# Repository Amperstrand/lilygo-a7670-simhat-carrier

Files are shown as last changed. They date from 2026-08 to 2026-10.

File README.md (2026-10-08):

# LILYGO T-A7670X + T-SimHat Combined Carrier

Parametric, 3D-printable internal electronics carrier that holds a
**LILYGO T-A7670X ESP32 modem board** and a **LILYGO T-SimHat (single-relay
variant)** side-by-side — mounted separately, wired together with jumpers —
for subsequent installation inside a waterproof enclosure.

Fully scripted in **Python + CadQuery**, driven by **manufacturer STEP/DXF
geometry** (no guessed dimensions), validated programmatically, and
regenerable with one command.

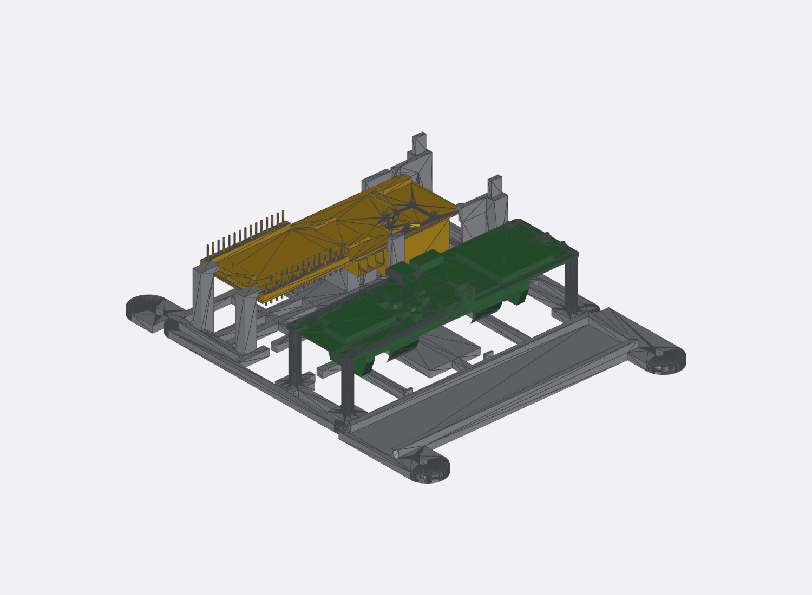
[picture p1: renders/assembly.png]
Assembly render


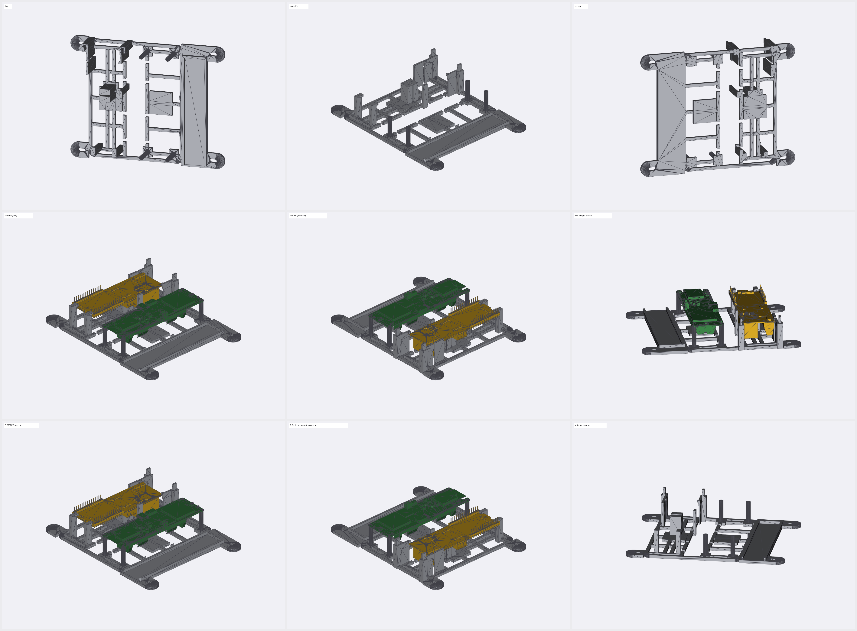
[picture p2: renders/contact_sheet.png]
Contact sheet


*T-SimHat (amber) flipped — relay down, headers up. T-A7670X (green) on
25 mm standoffs (18650 + holder underneath). LTE sticker-antenna tray on
the right edge (free air, coax clips on the frame rail). Full carrier
162 × 127.5 mm.*

## Explore in 3D

- **Interactive in-browser**: open any `.stl` on GitHub — it renders in a
  built-in 3D viewer you can rotate: [carrier](exports/lilygo_a7670_simhat_carrier.stl),
  [low-profile template](exports/lilygo_a7670_simhat_carrier_lowprofile.stl),
  [clip coupon](exports/simhat_clip_test.stl), [A7670 section](exports/sections/a7670_section.stl),
  [SimHat cage section](exports/sections/simhat_cage_section.stl).
- **Download & spin anywhere**: [assembly GLB](exports/lilygo_a7670_simhat_assembly.glb)
  and [carrier GLB](exports/lilygo_a7670_simhat_carrier.glb) open in Windows
  3D Viewer, macOS Preview, Blender, https://gltf-viewer.donmccurdy.com.
- **Renders**: served from GitHub Pages (CI rebuilds and redeploys them on
  every push — they are generated, not tracked): labeled views incl.
  per-board close-ups (`a7670_closeup.png`, `simhat_closeup.png`) and the
  contact sheet, at
  `https://amperstrand.github.io/lilygo-a7670-simhat-carrier/<name>.png`.
  Photo-textured hybrids are audited by `scripts/audit_photobake.py`
  (plane placement from placed STEP solids + fiducial centroids vs CAD
  truth).

## Key measured dimensions (from manufacturer CAD)

| Item | Value | Source |
|---|---|---|
| T-A7670X PCB | 33.071 × 110.54 × 1.2 mm | STEP cross-section + DXF dim `33.071` |
| T-A7670X mounting holes | 4 × Ø1.73 mm, 27.71 × 105.59 mm grid | DXF hole-callout dims, cross-checked vs STEP cylinders |
| T-A7670X mounting | **M1.6 screws into printed pilots** (default after the v0.3 print; `A7670_MOUNT="snap_plugs"` restores the screwless christmas-tree plugs) | Ø1.70 STEP holes, true centers measured off placed geometry |
| T-A7670X battery | 18650 + holder under board → 25 mm standoffs | user hardware + product docs |
| T-SimHat PCB | 33.0 × 94.8 × **1.0 mm** | STEP cross-section (verify with calipers: some batches 1.6) |
| T-SimHat mounting holes | **none** (hence snap-in cage) | STEP |
| T-SimHat relay | OMRON G5LE-class, 16.5 × 22.7 × 18.25 mm, single relay confirmed in STEP | STEP solids |
| LTE sticker antenna | ~110 × 20 mm sticker, 10–15 cm coax (user-measured; parametric `ANT_W`/`ANT_SLIDE`/`ANT_CABLE_L`) | — |

## Layout: rotated for short jumpers

The A7670X is mounted rotated 180° (`A7670_ROT_180`) so its pin-header
rails land at the same end as the SimHat's up-facing sockets: jumpers
cross the 16 mm wiring channel at ~15–25 mm instead of ~120 mm, and the
SMA antenna jacks sit a ~6 mm coax hop from the side-tray clips.

## Antenna side tray

The bundled full-band LTE sticker (~110 × 20 mm, SMA coax) slides into an
open tray on the +X frame edge, **between the two +X M3 ear slots** — free
air instead of under the 18650, so routing the coax up is trivial: it
drops into grooved posts on the tray's inner wall and runs along the
frame edge to the SMA jacks. Position was chosen by elimination, each
option boolean- or envelope-disproven: mid-channel (cage hardware cuts
the clear width to 17.3 mm vs 21.2 needed), a shelf over the SimHat
(blocks its removal lift), an end tray (237 mm vs the 175 mm bed).
**Caliper your sticker and set `ANT_W`/`ANT_SLIDE` before printing.**

## Print variants (all parametric)

| Variant | File | Print height | Purpose |
|---|---|---|---|
| **Calibration mini-coupon** | `exports/lilygo_calicheck_mini.3mf` | ~28 mm local, ~21 g, **~15 min** | **FIRST PRINT**: M1.6 pilot-hole ladder, SimHat thickness stair, antenna width slits, real snap-clip bay — calibrates every printer-dependent number before anything bigger |
| **Gridfinity fit-check tray** | `exports/lilygo_fitcheck_tray_gridfinity.3mf` | 33 mm pins / 7 mm body, ~17 g | second print: gauge pins verify the A7670 hole pattern with battery installed; SimHat outline + fence gauges; antenna channel; then clips onto any Gridfinity 3×4 baseplate |
| Full carrier | `exports/lilygo_a7670_simhat_carrier.stl` | ~34 mm, ~51 g | production holder (M1.6 screws, snap-caged SimHat, +X antenna tray) |
| Low-profile template | `exports/lilygo_a7670_simhat_carrier_lowprofile.stl` | **9 mm** | batteryless screw-fit + cage-outline check (relay/holder hang through the open frame); wall-mountable via M3 ear slots. Build: `CARRIER_PROFILE=low python scripts/build.py` |
| Snap coupon | `exports/simhat_clip_test.stl` | ~35 mm bay | pick XY clearance 0.20–0.50 (superseded for feel by the mini-coupon bay, still useful for clearance sweep) |
| Sections | `exports/sections/*.stl` | varies | iterate one region cheaply (A7670 plate / SimHat cage / antenna tray); volume-partition of the full carrier |

Print order: **full carrier** (one calibration pass already done; reprint the
calicheck mini only if you change `SIMHAT_PCB_XY_CLEAR` or the fence bite).
Design intent + audit table: `docs/design_spec.md`.

## Port access (validated)

Keep-clear service envelopes with zero printed-material interference:
USB-C plug, both SMA antenna connectors, SIM-tray swap zone, battery JST,
SimHat jumper-socket zone, relay/terminal cavity, the 18650 battery
keep-out under the A7670X, and auto-derived SimHat side/end-exit mating
envelopes (P1/P2, CAN/RS485 housings, terminal wire entry) — see
`analysis/interference_report.json` and `cad/connectors.py`.

## Status

`v0.4.0-validated` — 35/35 checks (full) + 28/28 (low) pass. v0.3 print
feedback addressed: M1.6 screws default, biting fence + snug end play
(rattle), fences off P1/CAN (mating-envelope enforced), antenna in the
+X side tray with coax clips. Carrier ~51 g PETG, 162 × 127.5 mm
(A1-mini safe).

## How the T-SimHat is held

No screws, no load on components:

- **4 support pads** (6 × 6 mm) contact **bare laminate only**, at grid
  positions verified clear of all 77 component solids in the STEP model
- **Fixed capture lip** at the far end (2 segments) hooks over the PCB top edge
- **2 flexible corner clips** at the near end snap over the PCB edge;
  flexure bends **in the XY print plane** (14 mm arms, ~1.6 % strain — PETG-safe)
- **3 fences** locate X/Y; board cannot slide or rotate
- **Removal:** press both release tabs → lift clip end 0.15 mm → slide out
  from under the lip (validated collision-free, incl. relay/SMD sweep paths)

## Quick start

```bash
uv venv .venv && uv pip install --python .venv/bin/python cadquery ezdxf trimesh numpy pillow lxml
.venv/bin/python scripts/analyze_step.py   # already run; regenerates analysis/*.json
.venv/bin/python scripts/build.py          # rebuilds exports/ (full + low) + renders/ + GLB/3MF
.venv/bin/python scripts/validate.py       # 18 checks -> analysis/interference_report.json
CARRIER_PROFILE=low .venv/bin/python scripts/validate.py   # low-profile checks (11)
```

## Printing

- **First print the coupon:** `exports/simhat_clip_test.stl` — four labeled
  clearance variants (0.20/0.30/0.40/0.50 mm, notch-counted). Pick the best
  fit, then set `SIMHAT_PCB_XY_CLEAR` in `cad/parameters.py` and rebuild.
- Full carrier: flat on the plate as modeled, no supports needed.
  PETG starting settings in `docs/print_settings.md`.

## Reference provenance

Manufacturer geometry lives in `references/` (MIT-licensed, © LILYGO),
copied from the forks in `vendor/` — see `references/PROVENANCE.md` for
exact upstream commits. Forks: `Amperstrand/T-SimHat`,
`Amperstrand/LilyGo-Modem-Series` (upstream: `Xinyuan-LilyGO/...`).

## Layout

```
cad/parameters.py     every dimension in one place (measured values load from analysis/*.json)
cad/holder.py         parametric model: base frame, standoffs, snap cage, ears
scripts/analyze_step.py   STEP -> geometry JSON (holes, PCB slab, components)
scripts/analyze_dxf.py    DXF dimension cross-check
scripts/build.py      regenerates exports/ and renders/
scripts/validate.py   interference, watertight, envelope, features, removal
exports/              carrier + coupon STL/STEP, assembly STEP
analysis/             machine-readable geometry + validation reports
docs/                 design decisions, assembly, print settings
```

All parameters — standoff height, board gap, clip geometry, ear positions,
pad locations, clearances — are in `cad/parameters.py`.

## Related project: Nucula NFC board enclosure

[`Amperstrand/nucula-enclosure`](https://github.com/Amperstrand/nucula-enclosure) —
the first outward port of this repo's methodology to a second measurement
front-end (KiCad instead of manufacturer STEP/DXF): a parametric,
3D-printable enclosure for the **Nucula board** (ESP32-C3 + NFC coil),
57/57 boolean checks green in its own CI. This repo's AGENTS.md prompt
library is the playbook it was built from — treat the two repos as
targets #1 and #2 of the same AI-assisted case-building framework.

## Repository

- GitHub: `Amperstrand/lilygo-a7670-simhat-carrier` (public)
- Branch: `cad/combined-carrier-v1`

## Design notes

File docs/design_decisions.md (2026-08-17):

# Design decisions

Rationale for the load-bearing choices. Dimensions live in
`cad/parameters.py`; measurements in `docs/reference_geometry.md`.

## Layout: side-by-side, long edges parallel

- A7670X 33.07 × 110.54 + SimHat 33.0 × 94.8 stacked end-to-end would exceed
  205 mm in Y — too long. Side-by-side with a 12 mm wiring channel:
  129.1 × 127.5 mm footprint, fits the 175 mm A1-mini safety envelope with
  >45 mm margin, and both boards stay serviceable from above.
- A7670X on +X, SimHat on −X; clip end of the SimHat faces the frame
  centerline so release tabs are between the boards (reachable, and jumper
  wires from the up-facing headers drop straight into the channel).

## A7670X mounting: M1.6 screws into printed pilots

- PCB holes are Ø1.73 mm (DXF-verified) → M1.6 is the honest fit. M2/M3
  would ream the board. Cross-checked STEP (Ø1.70 cylinders) vs DXF
  (Ø1.7296 callouts) — same centers.
- Pilot Ø1.30 × 8.5 mm deep in Ø4.6 bosses: self-tapping PETG thread,
  ~1.65 mm wall around the pilot. Blind pilots (1.5 mm floor) so screws
  never touch the enclosure below.
- Standoff height 13 mm: base 3.2 + bottom shield 8.5 + ~1.3 mm air. The
  parameter exists because boards with soldered 16 mm stacking headers need
  21 mm — one-line change.
- Board located by its 4 screws (not rails): no XY clearance fights, and
  unscrew → lift free is unobstructed (validated).

## T-SimHat: flipped, laminate-supported, snap-retained

Why flipped (relay down, headers up): the project wires the boards with
jumpers — headers must face up; relay/terminal side is the tall side that
benefits from a cavity; terminal-block screws face down but are only
touched at install time (mount carrier on enclosure screws AFTER wiring, or
leave relay-side access; see assembly doc).

Retention concept per requirements — open frame, no tray:

- **4 support pads** (6×6 mm) on bare laminate at v 34.5/42.0, u ±3.5 — the
  only ≥7 mm free window on both strips when checked against **all 77**
  component solids (first attempt used top-10 zones and validation caught
  real SMD collisions — kept the full-solid check).
- **Fixed capture lip** at the far end (v=94.8), 2 segments at u −13.5…−9
  and 9…13.5, engaging 2.6 mm over the PCB top. Segmented to keep the
  up-facing far-end SMDs (v 78.9–85.7) and header sockets (v 54–94.7,
  u ±14…16.5) clear; the two chosen windows are bare edge laminate.
- **2 corner clips** at the near end engage the PCB edge 1.0 mm over the
  top face. Flexure is **in the XY plane** (arm bends about Z): printed
  layers stay in-plane → maximum layer adhesion, no Z-axis peeling.
- **3 fences** (u sides at v 16/45/74 staggered) + lip + corner hooks give
  positive XY location and rotation lock; the board cannot translate or
  rotate (validated: seated interference zero against real STEP geometry).

## Snap-fit sizing (PETG, 0.4 mm nozzle)

- Arm: 14 mm long × 2.0 mm thick × 6 mm deep, tip deflection needed
  1.05 mm (per side) → ε ≈ 1.6 %, well under PETG's elastic envelope
  (~2–3 % design ceiling for repeated snapping). Long-gentle beats
  short-stiff: no brittle hooks anywhere.
- 0.8 mm plan-view lead-in chamfer on the hook inner corner: insertion
  ramps the arm outward instead of corner-on-corner scraping; the same
  ramp acts during release so tabs need only light finger pressure.
- Release: 2× fins (7 mm tall, 2 mm thick) standing at the arm roots,
  angled inward between the boards — thumb+finger squeeze or individual
  presses both work.
- Coupon-first strategy: 4 variants (0.20/0.30/0.40/0.50 mm XY clearance),
  notch-counted 1–4, before committing to the full print. Default 0.30 mm
  is the mid FDM-tolerance guess, not a claim.

## Structure & printability

- Base 3.2 mm rails/ribs (≥2 mm minimum per requirements; 3.2 = 8×0.4
  nozzle passes), open frame, cross ribs at ~28–56 mm pitch. Flat on plate,
  zero supports: every feature either grows from the plate (pads, fences,
  lip walls, standoff bosses) or is a horizontal ledge printed as bridging
  ≤2.6 mm wide (lip/clip ledges bridge in 2 perimeter passes).
- Rounded 6 mm outer corners; ears are the only outward features.
- Walls/ledges that touch PCBs: 0.2 mm vertical clearance everywhere
  (except the designed laminate contacts).

## Carrier↔enclosure interface (parametric, two options)

1. **4 M3 slotted ears** (16 mm wide, 7.5 mm slots) at the frame corners —
   positions/extent/slot orientation are parameters (`EARS`, `EAR_EXT`,
   `EAR_SLOT_*`); slotted = tolerant to unknown boss spacing. Ears sit at
   the frame extremes, not over any board → removal paths stay clear.
2. **VHB tape pads**: two 24×24 mm flat, unperforated landings under each
   board's centerline, deliberately kept hole-free.
No shell drilling required by either method.

## Wiring

- 8 cable-tie slots (3.6 × 7 mm) through both gap rails; jumpers from the
  SimHat headers cross the 12 mm channel to the A7670 edge pins without
  passing under any board.
- Nothing routes beneath the SimHat; the cavity is component space only.

## LTE sticker-antenna tray

- LILYGO publishes no CAD for the bundled full-band FPC sticker (web
  research: Quectel YF0006-class family, ~50×25 to ~60×45 mm), so the tray
  is parametric (`ANT_SLIDE`/`ANT_W`) with caliper-confirm defaults.
- Placement: −Y end, the only zone free of the SimHat clip anchors (+Y,
  x −5.7..0.3) and USB-C (+Y, x 13–31). Channels start outside the ring
  rail so the slide path never crosses base structure; a 5 mm coax notch
  passes the cable through the rail.
- Slide orientation: sticker slides along its SHORTER dimension — worst
  case 60×45 sticker still yields ≤175 mm total Y (default 45 → 173.5).
- Retention: friction channels + end stop + optional adhesive (sticker is
  self-adhesive; tray floor is the "keep it flat" guarantee). Flared
  mouths (1.5 mm) self-guide insertion; prints flat, no supports.
- Antenna sits ~80–100 mm from the modem's SMAs — beyond the near-field
  of the RF jacks; coax jump crosses the frame over the 3.2 mm rails.

## Port-access audit (validated, not assumed)

All tall structure (cage fences z→27.6, clip anchors z→40.4) lives on the
SimHat half; the A7670 half has only 3.2 mm rails below board level
(z 13+). Service envelopes — USB-C plug body (extends 12 mm past the +Y
edge), both SMA antenna connectors (16 mm past the +X edge), SIM-tray
swap zone, battery-JST headroom — are checked against the carrier solid
in validation: zero interference. Envelope coordinates derive from the
measured STEP component islands.

## A7670X rotation (180°) and battery lift

- Rotating the A7670X 180° about Z puts its 2×16 pin-header rails at the
  −Y end — the same end as the SimHat's up-facing sockets. Jumper length
  drops from ~120 mm to ~15–25 mm across the 16 mm channel. The SMA jacks
  then face the channel, feeding the antenna coax straight from the tray
  through the tie-slot row. The gap widened 12 → 16 mm for SMA plug
  bodies (~10 mm) facing each other.
- Envelope/hole positions derive programmatically
  (`_a7670_local_to_carrier`), never hand-rotated — the service envelopes
  and mounting holes follow `A7670_ROT_180` automatically.
- The 18650 + holder under the board sets standoff height: 25 mm =
  base 3.2 + cell/holder ~20.5 + air. Validated keep-out: 20 × 71 mm
  center strip under the board, zero carrier intersection. Without the
  holder, 13 mm; the fit-check template uses 9 mm.
- Rotating the SimHat instead was rejected: its pad/lip/fence placement is
  tied to component zones that don't survive a mirror (free laminate
  windows are asymmetric), while the A7670X is screw-located and rotates
  freely.

## Low-profile fit-check template + sections

- `CARRIER_PROFILE=low` builds a 9 mm open-frame template: bosses tall
  enough for a real M1.6 screw-fit, cage walls for outline/lip/fence
  position checks, cross ribs only at ±53.5 (outside every board
  underhang), no clips (the coupon covers snap feel), no tray/tape pads.
  Doubles as a flat wall-mount bracket via its 4 M3 ear slots.
- Sections (`exports/sections/`) are an exact volume partition of the
  finished carrier (validated: section volumes sum to the whole) for
  cheap per-region iteration. Not for reassembly — the full carrier is
  the assembly part.

## Gridfinity fit-check tray (ecosystem compatibility)

- Researched standards: **Gridfinity** (42 mm grid — the dominant open
  standard, full spec available), ToolGrid (newer, wedge interface, thinner
  adoption), honeycomb wall storage (wall-mounted, not desk). Chose
  Gridfinity for adoption + exact public numbers.
- Geometry per the canonical `kennetek/gridfinity-rebuilt-openscad`
  constants: 41.5 per-unit top (0.5 gap), dovetail base profile
  (35.6-wide bottom, 45°→vertical→45° to full width at z=4.75, corner radii
  0.8/3.75), built as a ruled ThruSections loft.
- Deliberate deviations (allowed by spec, documented): no stacking lip, no
  magnet holes, 1.2 mm walls, boards sit proud of the 7 mm rim — it's a
  gauge first, tray second.
- **Gauge-pin pattern**: when under-board parts (18650 holder 20.5 mm,
  relay 18.25 mm) exceed any printable pocket, seat the board on its
  lowest part and verify the hole pattern with drop-over pins instead of
  seat-on bosses. Pins Ø1.25 because the STEP models ~Ø1.35 drills (the
  Ø1.73 DXF figure is the plated spec) — pins gauge POSITION; diameter
  stays a caliper check.
- Layout conflict caught by slide-path validation: the compressed antenna
  channel initially crossed the gauge pins; boards shifted −14 mm and the
  channel moved to the +Y end. Relative gauge geometry unchanged.

## Mounting-ecosystem research (v0.4)

- **Gridfinity (42 mm)**: adopted for the fit-check tray. Python library
  `cq-gridfinity` (michaelgale, CadQuery-native) exists; we keep the
  ~40-line spec-exact base (boolean-validated against the canonical
  constants) — no new dependency, same geometry. Revisit the library if
  we ever generate baseplates/bins.
- **DIN-35 rail**: the classic shed/solar pattern (all charge controllers
  DIN-mount). Deferred: the unit's stated homes are a waterproof box or a
  wall box, both served by the M3 slotted ears/tabs + VHB pads. If the
  shed cabinet turns out DIN-rail-equipped, a clip-on ear pair is a
  parameter-level addition (TH35 top-hat profile, ~2 printed hooks),
  not a redesign.
- **19" rack / honeycomb wall**: rejected — wrong scale for a 133 mm
  carrier / wall-storage ecosystem is for tools, not wired electronics.

## Calibration strategy (v0.4)

Printer-dependent numbers (self-tap pilot Ø, PCB thickness, sticker
width, snap feel) are calibrated on a ~21 g throwaway coupon BEFORE the
17 g fit tray or the full carrier — see `docs/print_settings.md`. The
coupon's clip bay uses the production flip orientation and the shared
`_clip_arm_pts` profile, so what you feel there is what the carrier
does.

## Trade-offs accepted

- SimHat must slide 3.6 mm toward the clips during removal — pads are
  biased (v ≤ 42+3 = 45 < 46.9 sweep floor) so the down-facing SMDs never
  sweep into a pad; validated stage-by-stage.
- Ear flanges add 11 mm per side; total 129.1 mm still ≪ 175 mm.
- M1.6 fasteners are small to handle; alternative was reaming PCB holes —
  rejected.

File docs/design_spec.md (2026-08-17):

# Design specification & audit

The design intent in words, then an audit of the current model against
each sentence. Audit evidence: `analysis/interference_report.json`
(33/33 checks pass at time of writing).

## Spec

1. **The unit holds one LILYGO T-A7670X (with 18650 + holder fitted) and
   one single-relay LILYGO T-SimHat, mounted separately — never stacked —
   wired with jumper wires.**
   Audit: A7670 on 4× M1.6 bosses at DXF-verified hole coordinates
   (`features_present`); SimHat in snap cage, zero holes needed
   (`seated_simhat_interference = 0`); boards 16 mm apart.
2. **The SimHat is mounted upside-down (relay/terminal facing the
   carrier, headers up) supported only on bare PCB laminate; nothing
   loads components; removal is tool-less.**
   Audit: pads verified against all 77 STEP component solids + removal
   sweep (`component_clearance_min`, `simhat_toolless_removal` staged
   0 mm³); relay hangs in an open cavity (`battery`/relay keep-outs 0).
3. **Jumpers between boards are short and serviceable; connectors (USB-C,
   SIM, both SMA, battery JST, buttons, relay terminals) stay reachable.**
   Audit: A7670 rotated 180° so headers face the SimHat sockets (~15–25 mm
   jumpers); all six service envelopes 0 mm³
   (`connector_service_envelopes`).
4. **The LTE sticker antenna (110 × 20 mm) is held flat with its coax
   routed to the modem.**
   Audit: tray slide path + seated sticker 0 mm³ (`antenna_tray`);
   width gauges 19.8/20.2/20.6 on the calibration coupon.
5. **The carrier mounts inside a hardware-store waterproof box OR a
   wall-mounted box in a shed, without drilling the shell.**
   Audit: 4 adjustable M3 slotted points (2 corner ears + 2 tray-end
   tabs, all validated open) + two 24 × 24 VHB pad zones; DIN-35 rail
   evaluated and deferred (see `design_decisions.md`).
6. **It prints flat, support-free, in PETG on a Bambu A1 mini
   (≤175 mm XY), and iteration is cheap.**
   Audit: envelope 133.1 × 157.5 mm, z-min = 0, watertight single solid;
   variants: calicheck mini (~21 g), Gridfinity fit tray (~17 g),
   low-profile template, snap coupon, per-section STLs, full carrier.
7. **Every dimension that matters is parametric; the model regenerates
   deterministically and is provably self-consistent.**
   Audit: `cad/parameters.py` single source; measured values load from
   analysis JSONs; `deterministic_rebuild` hash-equal; sections sum to
   the whole (`sections_partition_volume`).
8. **Prints are calibrated before they are trusted.**
   Audit: calicheck coupon validates pilot-hole Ø, PCB thickness,
   antenna width, and real snap feel before any larger print
   (`calicheck_*` checks).

## Known gaps (deliberate, documented)

- Physical test-print feedback loop not yet closed (this release exists
  to close it).
- SimHat PCB thickness 1.0 mm is STEP-derived; coupon stair covers
  1.0–1.6.
- JST battery-plug envelope is from the STEP island; user photo pending.
- DIN-rail variant deferred until the enclosure decision is final.

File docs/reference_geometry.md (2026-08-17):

# Reference geometry — manufacturer CAD measurements

All values below were extracted programmatically from LILYGO's own STEP/DXF
files (see `references/PROVENANCE.md` for exact upstream commits). Nothing
was scaled from screenshots. Raw machine-readable output:
`analysis/a7670_geometry.json`, `analysis/a7670_dxf.json`,
`analysis/simhat_geometry.json`.

Method: cross-sectional area sweep + horizontal planar-face clustering
(PCB slab), thin-slab island sectioning (outline, component map), cylindrical
face enumeration (holes), DXF `DIMENSION` measurement extraction (hole
callouts). `scripts/analyze_step.py` and `scripts/analyze_dxf.py` regenerate
everything.

## T-A7670X (`T-A7670X-Board-3D.stp`, part name `SIM7000G_PCB_0415`)

LILYGO reuses one PCB outline across the SIM7000G/A7670 family; the STEP is
labelled SIM7000G but LILYGO ships it as the A7670 mechanical reference in
`dimensions/esp32/`.

| Measurement | Value | Source |
|---|---|---|
| PCB outline | **33.071 × 110.541 mm** | STEP cross-section; DXF dimension `33.071` agrees exactly |
| PCB thickness | 1.2 mm | STEP slab (planar faces z −1.2…0) |
| Mounting holes | **4 × Ø1.73 mm** (DXF callout 1.7296; STEP cylinder Ø1.700) | DXF hole dimensions + STEP cylinders, same centers |
| Hole centers, board-local from PCB lower-left corner | (2.591, 2.286), (30.328, 2.337), (2.616, 107.874), (30.328, 107.874) | STEP/DXF consensus |
| Hole grid | 27.71 × 105.59 mm, slightly asymmetric (DXF dims 27.737 / 27.711) | DXF |
| Header pin holes | 2 × 16 × Ø1.42 mm, 2.54 mm pitch, 38.10 mm row length, along both long edges | STEP cylinders + DXF dims |
| Corner fillets | R2.0 (these appear as Ø4.0 cylinders in naive face scans — they are outline fillets, **not** holes) | STEP |

Resulting screw size: **M1.6** (Ø1.6 screw in Ø1.73 hole). M2 would ream the
PCB holes; do not use.

Component envelopes (board-local, PCB top = z0, heights above/below surface):

| Zone | X | Y | Z extent | Note |
|---|---|---|---|---|
| Top shield/modem zone A | 2.7–26.9 | 10.7–34.9 | +0…2.4 | shield can |
| Top zone B (USB end) | 7.3–25.3 | 79.5–111.0 | +0…3.1 | USB + buttons end |
| Top zone C | 2.0–16.0 | 36.6–48.3 | +0…1.3 | low parts |
| Bottom shield | 6.1–27.1 | 12.7–101.8 | −0…8.5 | under PCB |
| Bottom stacking-header pins (optional HW) | 2 rails 2.54 pitch | both long edges | −0…15.0 | **only if 16 mm stacking headers are soldered** |
| SIM tray, SMA antenna jacks, USB-C | board edges (y≈80–104 end and long-edge x≈26–30) | | protrude past edges | island map in JSON |

## T-SimHat (`t-simhat-pcb.stp`, part name `T-SIMHAT-PCB`)

| Measurement | Value |
|---|---|
| PCB outline | **33.0 × 94.8 mm** |
| PCB thickness | **1.0 mm** (STEP slab; ⚠ verify with calipers — some production runs use 1.6 mm FR4; snap gap tolerates both but confirm before trusting the coupon result) |
| Mounting holes | **none** (hence the snap-in cage) |

Variant check: exactly **one** relay-class solid is present
(16.5 × 22.7 mm footprint, 18.25 mm tall ≈ OMRON G5LE-14 class), matching
the single-relay T-SimHat. The repo's second variant (T-SimHat-INA219) adds
a current-sensor assembly; this STEP does not contain it, so treat the
central strip and far end as populated territory (we did — see pads below).

Component envelopes (STEP-native coords; board is x −16.5…16.5,
y −94.8…0; the **y = 0 end faces the snap clips** on the carrier):

| Zone (STEP side) | X | Y (STEP) | v on carrier (=−Y) | Height | Carrier orientation |
|---|---|---|---|---|---|
| **Relay** (largest solid, 6805 mm³) | −16.5…0 | −29.2…−6.5 | 6.5…29.2 | 18.25 | faces DOWN into cavity |
| Terminal block (dual) | 5.5…16.0 | −15.8…0 | 0…15.8 | 13.8 | faces DOWN |
| SMD blocks ×2 | ±7.2…±16.5 | −49.4…−37.0 | 37.0…49.4 | 7.0 | faces DOWN |
| Small SMDs | 1.6…6.0 | −53.8…−50.5 | 50.5…53.8 | 2.8 | faces DOWN |
| Far-end SMDs ×2 | ±5…±9.8 | −85.7…−78.9 | 78.9…85.7 | 1.5 | faces DOWN |
| Stacking header sockets ×2 | ±14.0…±16.5 | −94.7…−54.0 | 54.0…94.7 | 8.1 | faces UP (jumper access) |
| Far-end low parts | −8…8 | −94.3…−87.0 | 87.0…94.3 | 2.0 | faces UP |

The only ≥7 mm window of bare laminate common to both u = ±3.5 strips is
**v 31.0–50.5** — this is where all four support pads sit (v 34.5 / 42.0),
additionally biased away from the removal slide path (pads top out below
v 46.9, the swept floor of the v 50.5–53.8 SMDs during board removal).

## Discrepancies & confidence notes

1. **A7670 STEP vs DXF**: hole Ø differs by 0.03 mm (1.700 vs 1.7296) — the
   DXF callout is the plated-hole spec; both round to M1.6. No other deltas.
2. **A7670 STEP models optional 16 mm stacking-header pins** below the PCB.
   Default standoffs assume they are NOT soldered (this project wires the
   boards with jumpers, never stacked). Set `A7670_STANDOFF_H = 21.0` in
   `cad/parameters.py` if your board has them.
3. **T-SimHat PCB thickness 1.0 mm** is STEP-derived and unusual (1.6 is
   common); the cage's 0.2 mm vertical clearances accept either, but verify.
4. The T-SimHat STEP is a fused single solid (no part tree); relay identity
   was inferred from envelope size/position, consistent with the repo's
   pinout photo (single G5LE-14, relay at IO32).

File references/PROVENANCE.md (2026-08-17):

# Reference geometry provenance

Files in this directory are copied unmodified from LILYGO's official
repositories (MIT license, © 2022 Xinyuan-LilyGO) for reproducibility.
Originals live in `vendor/` clones of the author's forks.

| File | Upstream repo | Upstream path | Fork commit |
|---|---|---|---|
| `T-A7670X-Board-3D.stp` | Xinyuan-LilyGO/LilyGo-Modem-Series | `dimensions/esp32/T-A7670X-Board-3D.stp` | Amperstrand/LilyGo-Modem-Series @ `a642844dff2b4194ff625eec34daf29f28bca126` |
| `T-A7670X-ESP32.dxf` | Xinyuan-LilyGO/LilyGo-Modem-Series | `dimensions/esp32/T-A7670X-ESP32.dxf` | same |
| `t-simhat-pcb.stp` | Xinyuan-LilyGO/T-SimHat | `3D_Model/t-simhat-pcb.stp` | Amperstrand/T-SimHat @ `c9dae24f97c24db5c88a56d937e629a0c6e2f193` |

Licenses: `LICENSE.LilyGo-Modem-Series`, `LICENSE.T-SimHat` (both MIT).

Forks are synchronized with upstream default branches at clone time; the
commit SHAs above pin the exact geometry used for each analysis run.

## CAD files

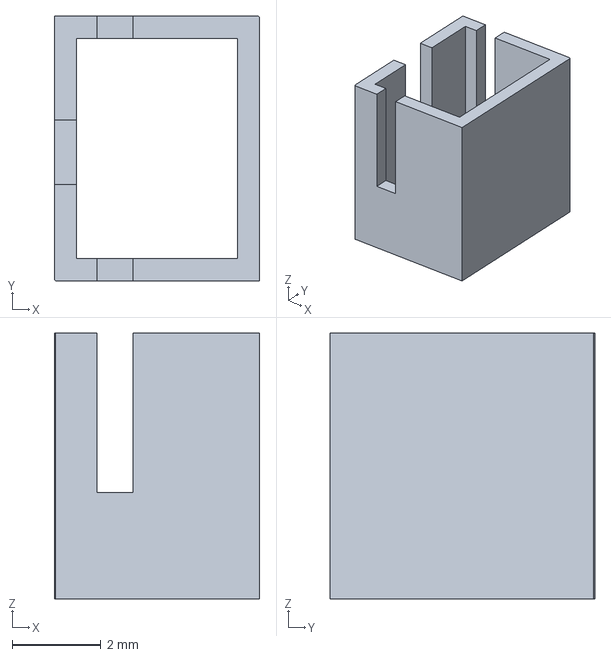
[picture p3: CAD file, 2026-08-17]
analysis/parts/a7670_geometry_top_components.step
4.63 x 5.97 x 6.00 mm

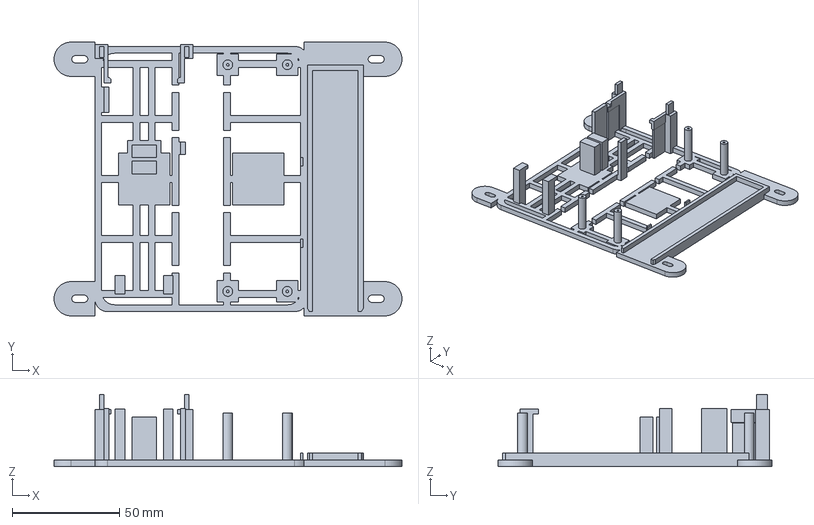
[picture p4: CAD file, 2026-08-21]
exports/lilygo_a7670_simhat_carrier.step
162.1 x 127.5 x 33.6 mm

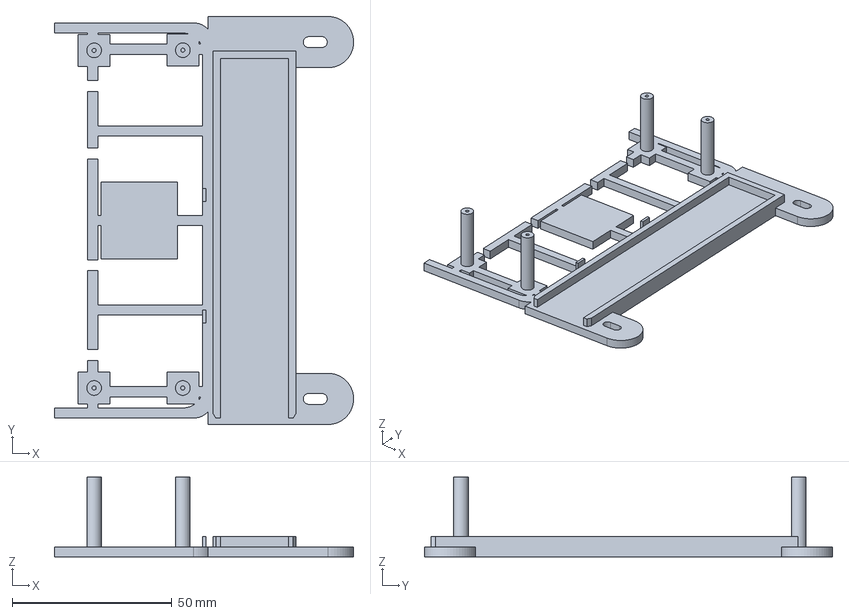
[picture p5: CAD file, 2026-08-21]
exports/sections/a7670_section.step
93.6 x 127.5 x 25.0 mm

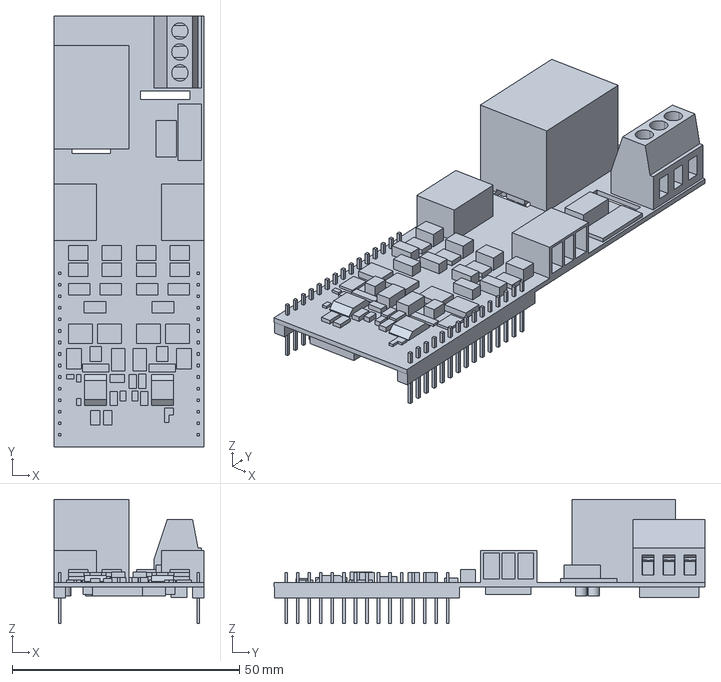
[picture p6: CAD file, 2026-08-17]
references/t-simhat-pcb.stp
33.0 x 94.8 x 27.4 mm

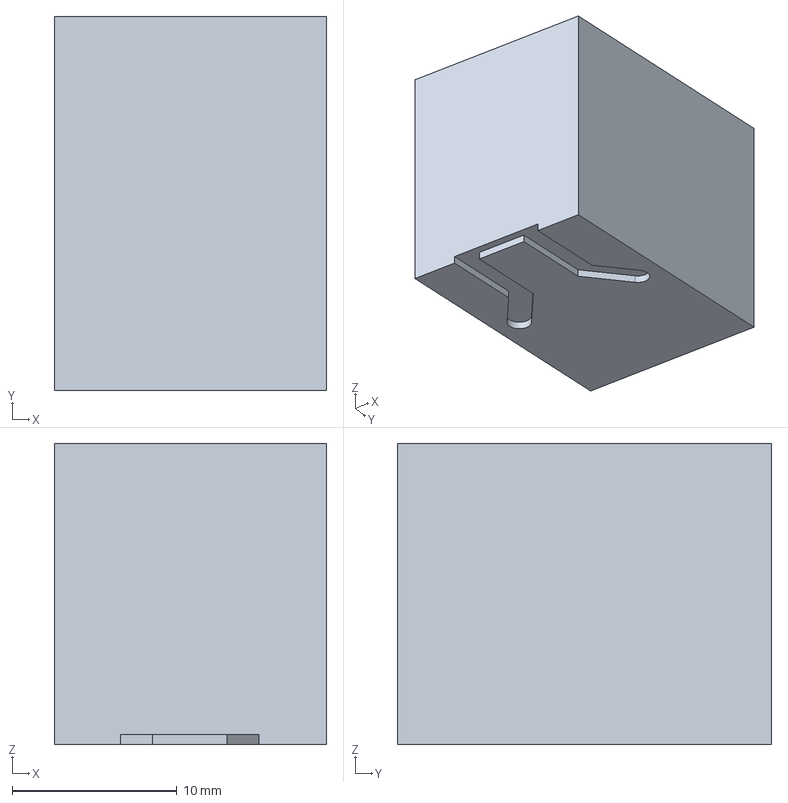
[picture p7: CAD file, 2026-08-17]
analysis/parts/simhat_geometry_top_components.step
16.5 x 22.7 x 18.2 mm

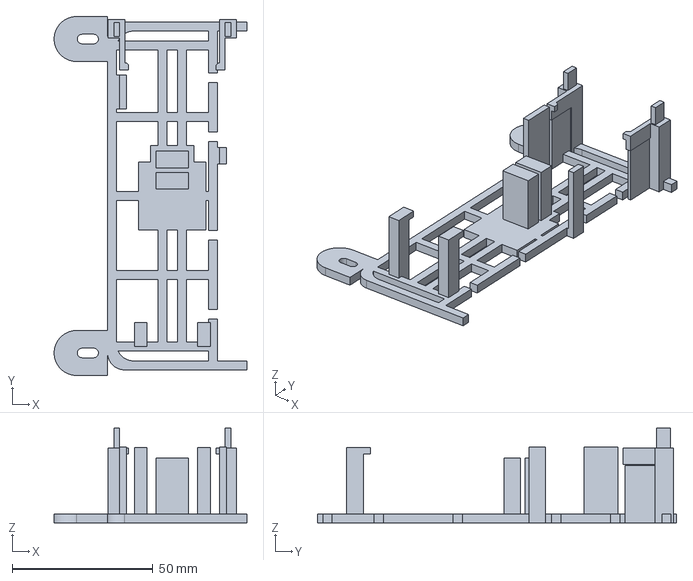
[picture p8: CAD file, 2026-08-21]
exports/sections/simhat_cage_section.step
68.5 x 127.5 x 33.6 mm

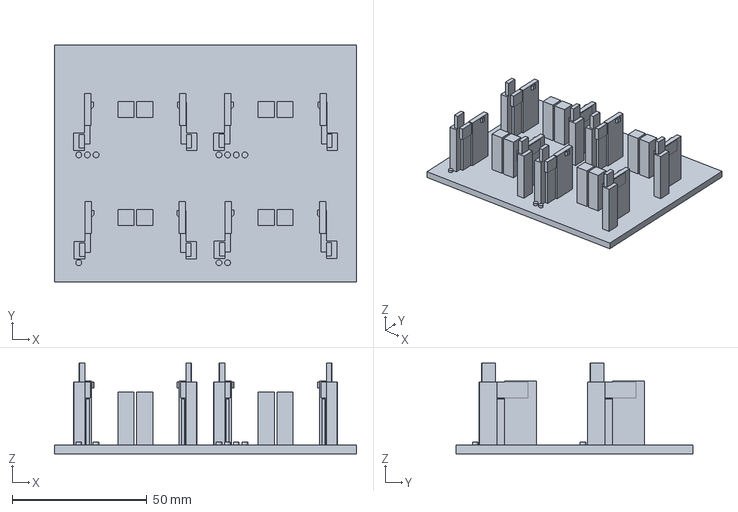
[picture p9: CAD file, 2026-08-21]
exports/simhat_clip_test.step
112.0 x 88.0 x 33.6 mm

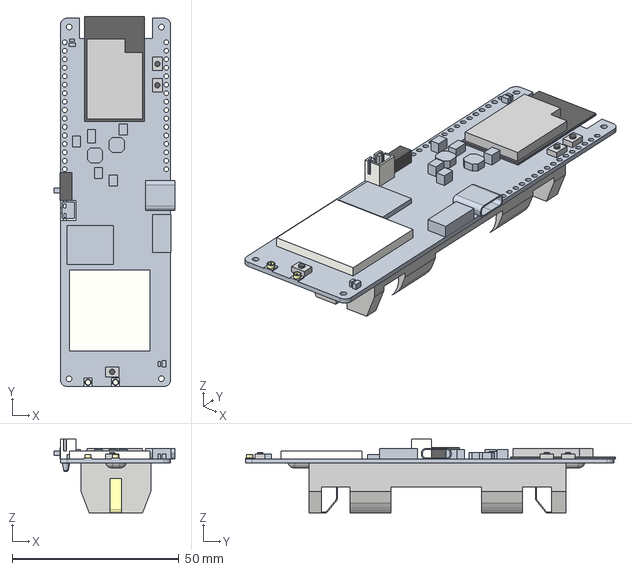
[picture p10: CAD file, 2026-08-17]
references/T-A7670X-Board-3D.stp
36.2 x 111.0 x 22.2 mm

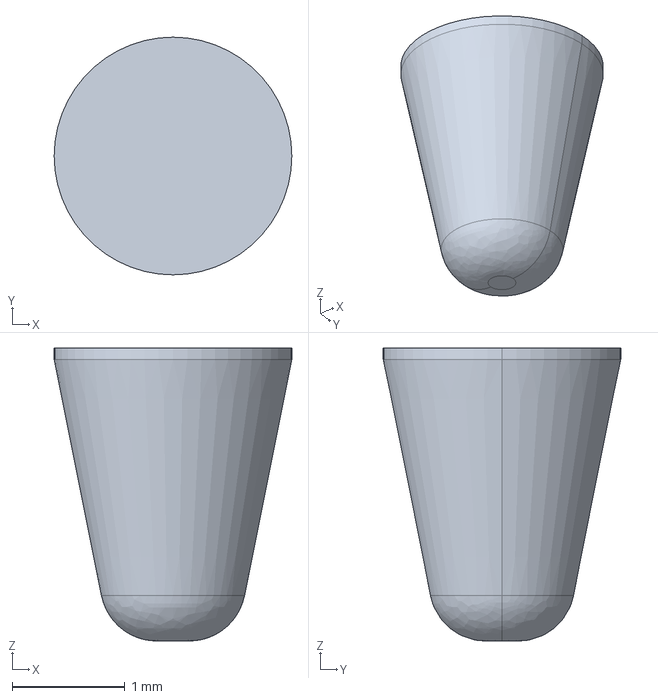
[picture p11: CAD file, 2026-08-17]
analysis/parts/a7670_geometry_bottom_components.step
2.11 x 2.11 x 2.60 mm

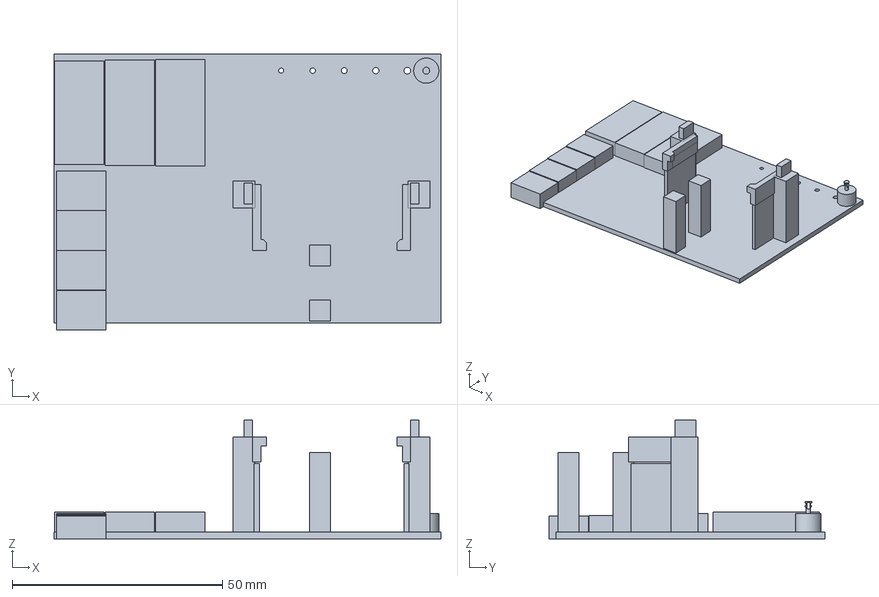
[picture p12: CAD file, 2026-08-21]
exports/lilygo_calicheck_mini.step
92.0 x 65.7 x 28.2 mm

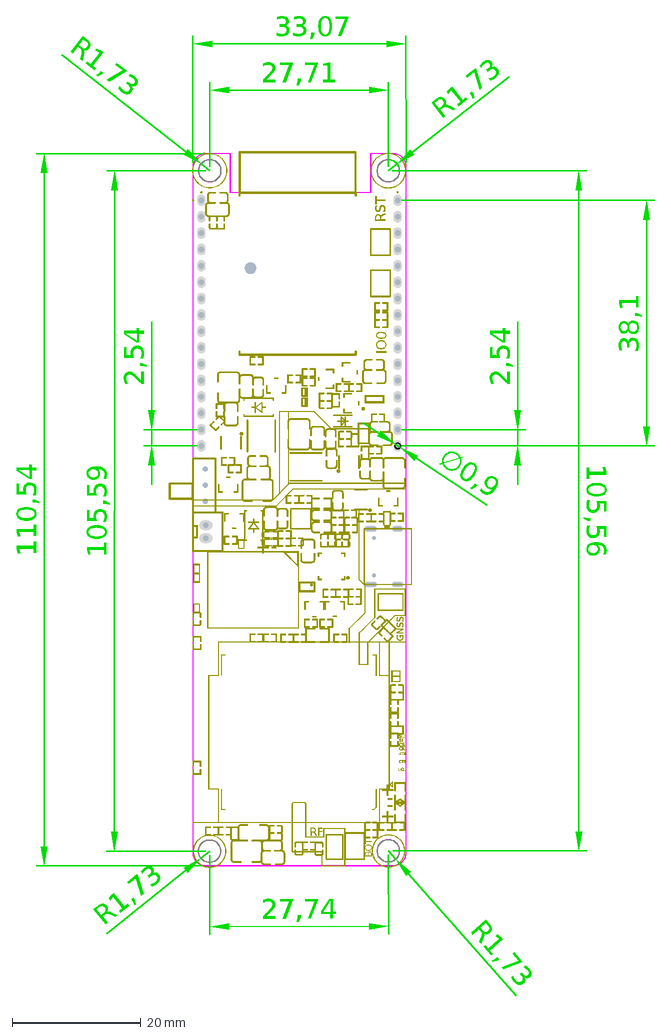
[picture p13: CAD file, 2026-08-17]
references/T-A7670X-ESP32.dxf
BOT
-
+
GNSS
RF
DCD
CTS
RTS
CK
CS
SI
SO
RST
IO0
R1,73
110,54
33,07
2,54
38,1
∅0,9
105,59
27,74
27,71
105,56

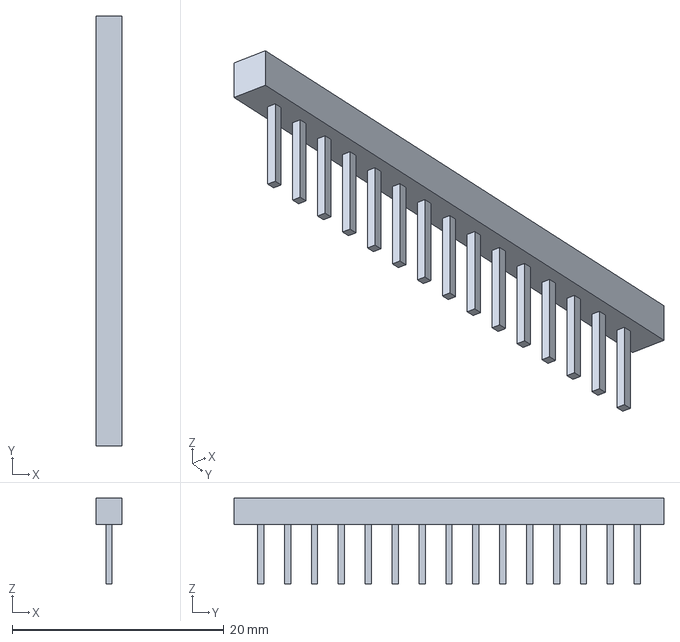
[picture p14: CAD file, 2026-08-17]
analysis/parts/simhat_geometry_bottom_components.step
2.50 x 40.6 x 8.10 mm

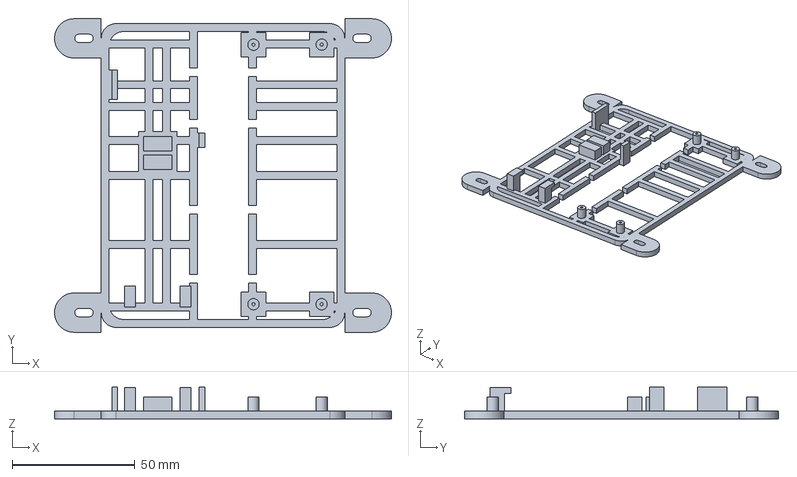
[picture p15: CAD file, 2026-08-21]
exports/lilygo_a7670_simhat_carrier_lowprofile.step
137.1 x 127.5 x 13.0 mm

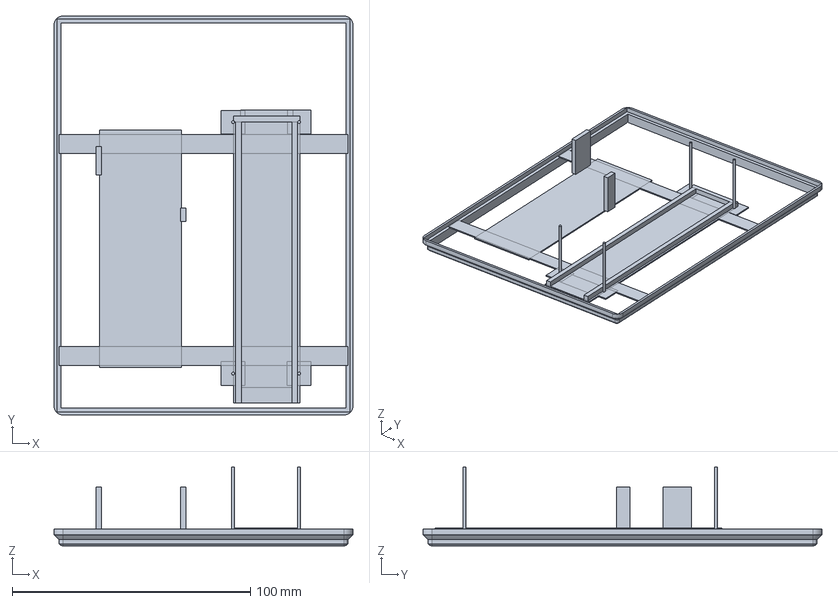
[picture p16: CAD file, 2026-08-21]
exports/lilygo_fitcheck_tray_gridfinity.step
125.5 x 167.5 x 33.1 mm

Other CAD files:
exports/lilygo_a7670_simhat_carrier.3mf
exports/lilygo_a7670_simhat_carrier.stl
exports/lilygo_a7670_simhat_carrier_lowprofile.stl
exports/lilygo_calicheck_mini.3mf
exports/lilygo_calicheck_mini.stl
exports/lilygo_fitcheck_tray_gridfinity.3mf
exports/lilygo_fitcheck_tray_gridfinity.stl
exports/sections/a7670_section.stl
exports/sections/simhat_cage_section.stl
exports/simhat_clip_test.stl

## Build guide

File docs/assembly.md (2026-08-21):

# Assembly & service guide

## Parts needed

| Part | Qty | Note |
|---|---|---|
| Printed carrier | 1 | PETG, settings in `print_settings.md` |
| M1.6 × 8 mm pan-head screws | 4 | A7670X (self-tap into printed pilots) |
| M3 screws + nuts or enclosure bosses | 4 | carrier→enclosure (or VHB tape instead) |
| Jumper wires (Dupont / harness) | as needed | boards are NOT plugged into each other |

## Install the T-SimHat (tool-less, do this first)

Orientation: **relay + terminal block face DOWN** (toward the carrier),
pin-header sockets face UP.

1. Tilt the board ~15°, relay side down.
2. Feed the FAR end (header-socket end, away from release tabs) under the
   fixed capture lip first, then lower the near end toward the support pads.
3. Press the near (clip) end down firmly with a thumb over each clip until
   both hooks click over the PCB edge. The board is now captured in X, Y,
   Z and rotation.

Routing tip: pre-attach jumper wires to the up-facing headers before
snapping the board in — the sockets are fully accessible either way, but
pre-wiring is faster.

## Install the LTE sticker antenna (tool-less)

The full-band sticker antenna (SMA coax) lives in the slide-in tray on the
+X (outer) edge of the A7670 half — free air, between the two +X mounting
ears, coax a ~6 mm hop from the modem's SMA jacks (v0.4; the v0.3
under-battery slot is still available as `ANT_POS = "under_battery"`).

1. Before printing, caliper the sticker and set `ANT_SLIDE` (dimension
   along the slide direction = the sticker's SHORTER side) and `ANT_W` in
   `cad/parameters.py`, then rebuild — the tray, frame and envelope check
   all resize from those two numbers.
2. Slide the sticker into the tray's chamfered mouth (-Y end) until it
   touches the +Y stop. It sits flat on the tray floor; the adhesive
   backing is optional — sticking it down makes it permanent.
3. Loop the coax over the frame edge and drop it into the two grooved
   posts on the tray's inner wall; it runs along the frame to the SMA
   jacks with no strain.
4. Screw the SMA plug onto the modem's MAIN RF jack (either SMA if you
   also use GNSS). Route spare coax through the cable-tie slots.

## Install the T-A7670X

Orientation note: the board mounts **rotated 180°** (`A7670_ROT_180`) so
its pin headers face the SimHat sockets across the wiring channel —
jumpers stay ~15–25 mm. Mounting is **M1.6 screws by default** (v0.4; the
v0.3 snap plugs printed loose and are demoted to the optional
`A7670_MOUNT = "snap_plugs"` variant).

1. Fit the 18650 into the board's under-side holder first (if used).
2. Lower the board **straight down** over the four standoffs near the
   clip-end and USB-end corners; the bosses register the holes.
3. Drive four M1.6×6 self-tappers into the printed Ø1.30 pilots. Snug,
   not gorilla-tight — the pilots are the thread.
4. USB-C (away from the SimHat), SIM tray, buttons, battery JST and
   both SMA jacks stay accessible.

## Wire the boards

- Jumpers run from the SimHat headers across the 12 mm center channel to
  the A7670 edge pins. Nothing passes under either board.
- Use the 8 cable-tie slots in the channel rails for bundling/strain
  relief — 3.6 × 7 mm slots take standard mini cable ties.
- Antennas: SMA jacks are clear on the board's long edges; route cables
  out over the frame edge nearest your enclosure cable glands.

## Mount the carrier in the enclosure

- **Screws:** 4 M3 slotted points. Two corner ears at the +Y end; two
  slotted tabs on the antenna-tray end wall at −Y (slots run fore-aft, so
  boss spacing tolerance is ±3 mm on both axes). Loosely fit all four,
  align, tighten.
- **Tape instead:** two 24 × 24 mm flat pads under the board centerlines
  accept VHB tape; frame underside is flat there by design.
- **Low-profile template as a wall bracket:** the 9 mm template can be
  screwed flat against an enclosure wall through its 4 M3 ear slots;
  boards face outward. (No snap clips on that variant — retention is
  screws for the A7670X and gravity/lip for a laid-in SimHat; use the full
  carrier for proper tool-less retention.)

Do not drill the enclosure shell — either method works with stock bosses
or a flat internal surface.

## Service

**Remove the T-SimHat** (no tools): squeeze both release fins toward each
other (or press each outward individually) → hooks release the PCB edge →
lift the clip end ~0.2 mm → slide the board ~4 mm toward the clips (away
from the fixed lip) → lift out. The relay never touches anything on this
path (validated against the manufacturer STEP).

**Remove the T-A7670X**: unscrew 4 × M1.6 → lift straight up. Clearance
above is unobstructed.

**Terminal-block wiring note**: the relay's screw terminals face down
toward the base. Wire them BEFORE snapping the SimHat in, or remove the
board (10 s, tool-less) to change terminal wiring later.

## What to check before first trust in the print

1. Coupon fit result transferred to `SIMHAT_PCB_XY_CLEAR` (if not 0.30).
2. Caliper the SimHat PCB thickness — if it is 1.6 mm not 1.0 mm, increase
   `SIMHAT_PCB_T_CLEAR` to taste (0.2 mm default still functions; the
   cage gap self-adjusts by design margin) and rebuild.
3. Caliper the antenna sticker (L × W) and coax; set `ANT_W` (long dim),
   `ANT_SLIDE` (short dim), `ANT_CABLE_L` and rebuild.
4. Confirm whether your A7670X has the 18650 holder (default assumes yes,
   25 mm standoffs) and whether stacking-header pins are soldered (25 mm
   already clears them).
5. Optional 15-minute sanity print: the low-profile template
   (`exports/lilygo_a7670_simhat_carrier_lowprofile.stl`) — lay each board
   on it: A7670X holes should drop over the 4 bosses for a real M1.6 screw
   fit; SimHat outline should match the pad/lip/fence footprint (relay
   overhangs through the open frame — test at a desk edge).

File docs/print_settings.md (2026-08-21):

# Print settings — starting values (Bambu Lab A1 mini, PETG, 0.4 mm)

These are **conservative starting points, not universal truths**. Tune to
your filament and printer. Both parts print **as oriented in the STL** —
carrier base flat on the plate, no rotation, **no supports**.

## v0.4 print order (post-calibration)

One calibration pass is already done (v0.3 print). Default order now:

1. **Full carrier** — `exports/lilygo_a7670_simhat_carrier.stl`
   (~51 g, 4–5 h). 0.20 mm / 3 walls / 4 top–3 bottom / 12–15 % gyroid.
   Enable thin-wall detection (fence walls and coax-clip posts have
   single-perimeter regions).
2. Reprint the **calibration mini-coupon**
   (`exports/lilygo_calicheck_mini.3mf`, settings below) ONLY if you
   changed `SIMHAT_PCB_XY_CLEAR`, `SIMHAT_FENCE_BITE`, or the clip
   geometry — the screws default removed the pilot-hole question, and
   the coupon never gauged the fence bite anyway.
3. The Gridfinity fit-check tray remains useful as a desk-tray gauge for
   the A7670 hole pattern with battery installed; optional.

## Calibration mini-coupon (when needed) — `exports/lilygo_calicheck_mini.3mf`

**~21 g, ~13-18 min, one plate, no supports, no brim.** Open the 3MF in
Bambu Studio and slice at 0.28-0.32 mm / 2-3 walls / 5-10 % gyroid.
Enable thin-wall detection (the Ø1.2-1.6 gauge holes and clip arms need
single-perimeter walls).

Layout (as sliced, plate on bed):

| Feature | Where | What to report back |
|---|---|---|
| M1.6 pilot-hole ladder Ø1.20→1.60 | top-right row, left→right increasing | smallest Ø an M1.6 screw taps into snugly |
| PCB thickness stair 1.0/1.2/1.4/1.6 | left wall, bottom→top | which slit the T-SimHat edge slides into freely |
| Antenna width slits 19.8/20.2/20.6 | left-of-center tall blocks, bottom→top | which slit the sticker slides through with light drag |
| Snap-clip bay (production geometry) | right side | does the SimHat clip-end (relay DOWN, as installed) snap under the hooks and release with finger pressure? |

This coupon calibrates the four printer-dependent numbers the whole
design leans on. Report the three numbers + clip feel, then the full
carrier prints with confidence.

## Second: Gridfinity fit-check tray — `exports/lilygo_fitcheck_tray_gridfinity.3mf`

Open the **3MF directly in Bambu Studio** (File → Open) and slice with:

| Setting | Fast (target ~15 min) | Balanced |
|---|---|---|
| Layer height | 0.32 mm | 0.28 mm |
| Wall loops | 2 | 3 |
| Top / bottom | 3 / 2 | 4 / 3 |
| Infill | 5 % Gyroid | 10 % Gyroid |
| Speeds | default Draft profile | default profile |
| Brim / supports | none / none | none / none |

Model is ~16.7 g of PETG → expect **12–18 min** on an A1 mini. Enable
"Arachne"/thin-wall detection so the Ø1.25 gauge pins slice cleanly (they
print as a single perimeter spiral). The tray is deliberately NOT durable:
1.2 mm walls, 0.6 mm floors.

**What it verifies (in one print):**
1. A7670X **hole pattern** — drop the board (battery installed is fine)
   over the 4 pins; all 4 engage = positions correct. Pin Ø1.25 fits the
   modelled drill; the plated Ø1.73 spec stays a caliper/screw check.
2. A7670X **outline** — board lands on its support rib without touching
   fences/walls.
3. SimHat **outline + cage XY** — relay-down board rests flat, edges at
   0.3 mm from the three fence gauges.
4. Antenna sticker **fits the 110 × 20 channel** and slides to the stop.

After the check it stays useful: it clips onto any **Gridfinity 3 × 4
baseplate** (or sits on the desk) as a tray for the boards + antenna
during assembly. Boards sit proud of the low walls by design.

## Full carrier — `exports/lilygo_a7670_simhat_carrier.stl`

| Setting | Start value | Why |
|---|---|---|
| Layer height | 0.20 mm | ledges/bridges are 2.2–2.6 mm; even layers matter more than speed |
| First layer | 0.24 mm | |
| Wall loops | **4** (1.6 mm) | rails are 3.2 mm → solid-ish walls, clips get perimeter strength |
| Top/bottom | 4 / 4 | base is 3.2 mm → fully printed top+bottom shells |
| Infill | 15 % Gyroid | frame carries load in the rails, not the infill |
| Filament | PETG | as specified; do NOT print clips in PLA (brittle at flex roots) |
| Nozzle/bed | 250 °C / 80 °C | typical PETG start point |
| Cooling | 30–50 % fan | some fan helps clip detail; too much hurts layer bonding |
| Elephant foot | 0.2 mm | keeps outer rails/ears within tolerance |
| Brim | **Not needed** | large flat base, low warp risk |
| Supports | **None** | all overhangs are ≤2.6 mm bridges or grow from the plate; antenna tray walls are 4.5 mm vertical flanges — support-free |
| Orientation | As exported | clip arms flex in-plane with layers — do not reorient |

Clip-critical note: the snap arms are 2.0 mm thick = 4 perimeters at 0.4 mm
nozzle, no infill dependence. If you must choose, favor **more walls over
more infill**.

## Snap-fit test coupon — `exports/simhat_clip_test.stl` (print this FIRST)

Same settings as above; takes ~20 g of filament. Four bays:

| Bay position | Notches | XY clearance |
|---|---|---|
| bottom-left | 1 | 0.20 mm |
| bottom-right | 2 | 0.30 mm |
| top-left | 3 | 0.40 mm |
| top-right | 4 | 0.50 mm |

Test with a scrap of PCB-material of matching thickness (or the SimHat
itself, relay side down, gently): the target bay holds the board with a
clear click, releases with light finger pressure on the fins, and shows no
white stress marks at the flex roots after ~10 cycles. Then set
`SIMHAT_PCB_XY_CLEAR` in `cad/parameters.py` to the winning value and
rebuild (`python scripts/build.py`).

## Low-profile fit-check template — `exports/lilygo_a7670_simhat_carrier_lowprofile.stl`

Same material settings; only 9 mm tall, ~15–20 minutes, ~8 g. Purpose:
verify XY dimensions and the M1.6 hole pattern with real screws before
committing to the 2 h full print. Lay the A7670X on the 4 bosses (18650
holder hangs through the open frame); sight the SimHat outline against
the pad/lip/fence footprint at a desk edge (relay overhangs below).

## Sections — `exports/sections/*.stl`

Same settings; each section is a standalone printable piece (A7670 plate,
SimHat cage, antenna tray + end wall with its 2 mounting tabs). Use to
re-print just one region after a parameter tweak instead of the whole
carrier. They are a volume-partition of the full carrier — iterate and
verify with them, then rebuild the whole.

## After-print checks

- Caliper the SimHat bay: PCB should slide in with the coupon's chosen feel.
- Inspect clip roots for delamination lines (if present: raise bed/nozzle
  temp 5 °C, slow outer walls to 50 %).
- M1.6 pilots: an M1.6 screw should need 2–3 firm turns to bite; if it
  spins, drop `A7670_PILOT_D` to 1.25 and rebuild.

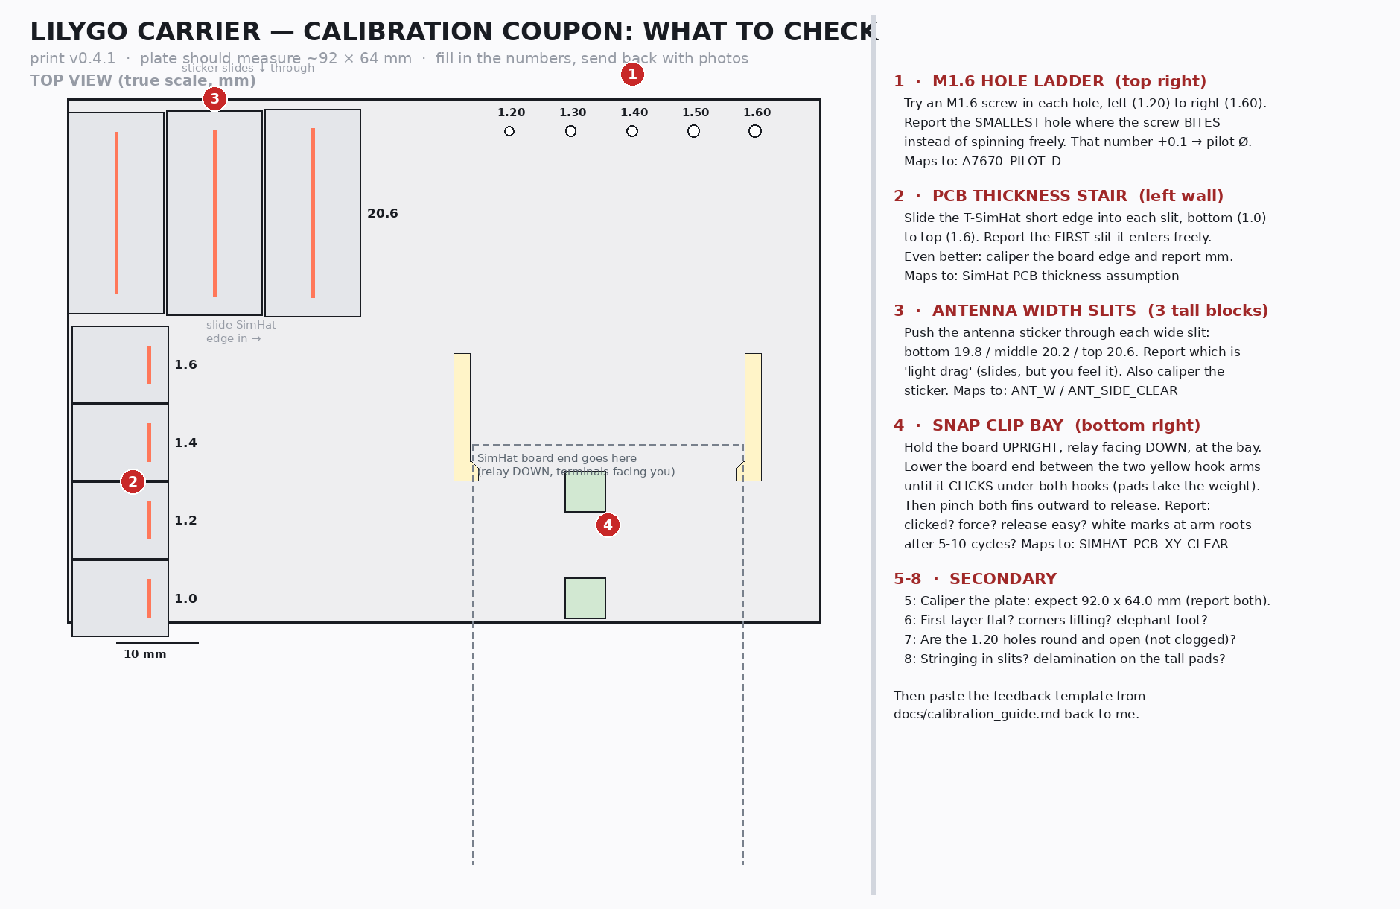
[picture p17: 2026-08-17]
exports/lilygo_calicheck_guide.png

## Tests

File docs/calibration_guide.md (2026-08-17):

# Calibration coupon — check & feedback guide

Companion image: `exports/lilygo_calicheck_guide.png` (same picture is
served on the LAN). Work through the four numbered tests in order, then
the secondary checks, then paste the template at the bottom back to me
(filled in) together with photos.

## ① M1.6 hole ladder — top-right, 5 holes left→right

The holes are Ø 1.20 / 1.30 / 1.40 / 1.50 / 1.60 mm (labels under each).

**Do:** try an M1.6 screw in each hole, left to right. In the small ones
it should bite (feels like it's cutting a thread); in the big ones it
spins freely.

**Report:** the smallest hole where the screw still *bites*.
That number +0.1 mm becomes the self-tap pilot diameter in the 8.5 mm
deep standoff bosses (`A7670_PILOT_D`). The coupon plate is thin, so
bite here is conservative — the deep boss grips better.

## ② PCB thickness stair — left wall, bottom→top

Four horizontal slits, heights 1.0 / 1.2 / 1.4 / 1.6 mm.

**Do:** slide the T-SimHat's short edge into each slit from the side,
bottom to top.

**Report:** the first slit the edge enters freely (no forcing). Even
better: caliper the board edge and give me the number. This resolves
whether your board is the STEP's 1.0 mm or the more common 1.6 mm.

## ③ Antenna width slits — three tall blocks, bottom→top

Wide vertical slits, widths 19.8 / 20.2 / 20.6 mm.

**Do:** push the antenna sticker through each slit in turn.

**Report:** which width feels like "light drag" — slides through but you
feel contact. Also caliper the sticker (should be ~110 × 20). Sets the
tray's running clearance (`ANT_SIDE_CLEAR`).

## ④ Snap-clip bay — bottom-right, two yellow hook arms

This bay reproduces the production snap exactly: same profile, same
clearance, board at the same height, relay DOWN as installed.

**Do:**
1. Hold the T-SimHat upright over the bay, **relay/terminal side facing
   down** (components toward the plate).
2. Lower the board's terminal-block end between the two hook arms until
   it **clicks** under both hooks. The two green pads are where the board
   rests.
3. Pinch both release fins outward (away from each other) and lift the
   board out. Repeat 5–10 times.

**Report:** did it click? insertion force (gentle / firm / couldn't);
release easy? any white stress marks at the arm roots after cycling? a
visible gap between hook and board when seated? If it's too tight, the
full carrier moves to 0.40 mm clearance; too loose, 0.20.

## ⑤–⑧ Secondary checks

- **⑤ Plate size:** caliper X and Y. Model says 92.0 × 64.0 mm. More
  than ±0.3 mm off → we add XY shrinkage compensation globally.
- **⑥ First layer:** flat on a table? corners lifting? obvious elephant
  foot (measure plate thickness at a corner; model is 1.6 mm)?
- **⑦ Smallest holes:** are the Ø1.20 holes round and open, or partially
  clogged?
- **⑧ General quality:** stringing across slits, delamination lines on
  the two tall pads (19 mm — the same height class as the carrier cage).

## Feedback template (copy, fill, paste back)

```
CALIBRATION FEEDBACK (coupon v0.4.1)

1. M1.6 ladder:  smallest biting hole = ____ (1.20/1.30/1.40/1.50/1.60)
   notes: ________________________________________________

2. SimHat thickness: first free slit = ____ mm
   caliper of board edge = ____ mm

3. Antenna: free at 19.8? ___   light drag at 20.2? ___   20.6? ___
   sticker caliper = ____ × ____ mm

4. Clip bay:  clicked? Y/N    force: gentle/firm/impossible
   release: easy/hard    white marks after cycling? Y/N
   hook gap when seated: none/small/large

5. Plate: X = ____ mm   Y = ____ mm   (target 92.0 × 64.0)

6. First layer flat? Y/N   elephant foot? Y/N   corner thickness = ____ mm

7. Ø1.2 holes open+round? Y/N

8. Stringing / delamination / other: ________________________________

Photos attached: top view, hole ladder close-up, board clicked into bay
```

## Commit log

2026-08-17 cad: combined carrier v1 — parametric model, analysis, validation, exports
    - Measure both boards from manufacturer STEP/DXF (no guessed dims):
    A7670 33.071x110.54mm, 4x M1.6 holes (Ø1.73 DXF-verified);
    SimHat 33x94.8x1.0mm, no holes, single relay confirmed in STEP
    - Parametric CadQuery carrier: M1.6 standoff bosses, laminate-only
    support pads (verified vs all 77 component solids + removal sweep),
    XY-plane snap clips w/ release tabs, capture lip, fences, cable-tie
    slots, M3 slotted mounting ears, VHB tape pads
    - 14/14 validation checks pass: zero interference seated, tool-less
    SimHat removal (lift/slide), watertight STL, deterministic rebuild
    - Snap-fit test coupon: 4 clearance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
    [T-A7670X-Board-3D.stp, T-A7670X-ESP32.dxf, a7670_geometry_bottom_components.step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]
2026-08-17 feat: LTE sticker-antenna slide-in tray + validated port-access envelopes
    - Parametric antenna tray at -Y end (ANT_SLIDE/ANT_W; no manufacturer CAD
    for the sticker -> caliper-confirm defaults 45x50): flat floor keeps
    sticker flat, flared channel mouths self-guide, end stop + friction
    retain, 5mm coax notch through the ring rail to the modem SMAs
    - Slide-along-short-dimension keeps worst-case 60x45 sticker inside the
    175mm A1-mini envelope (default total 129.1 x 173.5)
    - Port-access audit formalized: USB-C plug / SMA x2 / SIM swap / battery
    JST service envelopes all zero-interference vs carrier solid
    - Validation now 17/17: antenna slide path + seated sticker clear
    - Docs: antenna i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
    [a7670_geometry_bottom_components.step, a7670_geometry_top_components.step, lilygo_a7670_simhat_carrier.3mf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]
2026-08-17 feat: v0.2.0 — battery lift, board rotation, low-profile template, sections, GLB/contact-sheet, AGENTS lessons
    Hardware-driven changes:
    - A7670 180-deg rotation (A7670_ROT_180): headers now face the SimHat
    sockets across a 16mm channel -> jumpers ~15-25mm instead of ~120mm;
    SMA jacks face the channel; envelopes/holes derive via one transform
    - 18650 battery holder clearance: 25mm standoffs + validated 20x71mm
    keep-out under the board (13mm without holder, documented)
    - Antenna tray resized to user-measured 110x20mm sticker (slides along
    short dim, lies along X), ANT_CABLE_L param; -Y mounting points moved
    from corner ears to tray-end slotted tabs (ears blocked the 110mm
    tray mo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
    [a7670_section.step, a7670_section.stl, antenna_tray_section.step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]
2026-08-17 feat: Gridfinity 3x4 fit-check tray — 15-min first print, opens in Bambu Studio
    - cad/fitcheck.py: 125.5x167.5 (3x4 unit) Gridfinity tray with the exact
    carrier XY layout; dovetail base per canonical spec constants
    (kennetek/gridfinity-rebuilt-openscad): 41.5/unit, 45-vert-45 profile
    to z4.75, r0.8/3.75, ruled ThruSections loft
    - Gauge-pin pattern: 4x Ø1.25x28 pins verify A7670 hole POSITION with
    battery installed (holder rests on support rib; STEP drills ~Ø1.35,
    DXF Ø1.73 is plated spec); SimHat relay-down outline + 3 fence gauges;
    110x20 antenna channel with slide-to-stop
    - Caught by validation during design: pins vs antenna channel collision
    after layout compression ->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
    [a7670_section.step, antenna_tray_section.step, lilygo_a7670_simhat_carrier.3mf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]
2026-08-17 feat: v0.4.0 — calibration mini-coupon, spec audit, public repo, ecosystem research
    - cad/calicheck.py: ~21g / ~15min throwaway calibration coupon:
    M1.6 pilot-hole ladder (Ø1.20-1.60), SimHat thickness stair
    (1.0/1.2/1.4/1.6), antenna width slits (19.8/20.2/20.6), and a
    production-orientation snap bay (real flip, real support height,
    shared _clip_arm_pts profile — cannot drift from carrier geometry)
    - Layout bugs caught by validation during bring-up (each fixed):
    Y-flip mirrors u (STEP x != board u) -> relay at u 0..16.5, pads
    moved to the true free strip u -5.5..0; rotZ 'fix' made the
    placement mirrored/unrealizable -> bay features use y=oy-v with a
    pure-translation boa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
    [a7670_section.step, antenna_tray_section.step, lilygo_a7670_simhat_carrier.3mf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]
2026-08-17 fix: printable clip arms — support pedestals + floating-cantilever lint
    - Bambu Studio flagged floating cantilevers: the XY-flexure clip arms
    sit ~20mm above the plate, root-supported only -> first arm layer
    extrudes into air and droops
    - Fix: SIMHAT_ARM_PEDESTAL — 1.2mm wall under each arm free span (carrier
    clips, clip coupon bays, calicheck bay), top 0.3mm below the arm
    underside so the flexure is untouched in service; fuses at the anchor
    - New printability lint (validate.py printability_scan): z-slab island
    scan, 2-slab lookback (0.3mm gaps pass), edge-anchored sheets classified
    as bridge sheets not failures, bed zone skipped. All four parts: 0
    floating cantilevers; tra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
    [a7670_section.step, antenna_tray_section.step, lilygo_a7670_simhat_carrier.3mf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]
2026-08-17 docs: calibration feedback guide — annotated map image + fill-in template
    - scripts/make_guide.py: generates renders/calicheck_guide.png (also
    served at exports/lilygo_calicheck_guide.png) — true-scale top-view
    schematic drawn from cad/calicheck constants (no drift), numbered
    badges 1-4, red slit callouts, clip-arm outlines from the shared
    _clip_arm_pts, dashed board ghost; right panel = the 4 tests + 4
    secondary checks
    - docs/calibration_guide.md: step-by-step per test incl. what each
    number maps to (A7670_PILOT_D, thickness, ANT_SIDE_CLEAR,
    SIMHAT_PCB_XY_CLEAR) + copy-paste feedback template
    - element placement verified programmatically (vision svc flaked)
2026-08-17 fix: carrier pads recentered after coupon feedback; SimHat cutouts documented
    User calibration feedback (coupon v0.4.1, printed):
    - Snap bay: 'snaps firmly in place, just perfect' -> XY clearance 0.30
    confirmed, no change
    - Antenna: fits between 19.8/20.2 slits -> ANT_SIDE_CLEAR 0.5 stands
    - Holes: all open; test object snug in 1.20, easy in 1.40 -> pilot 1.30
    stands (pending screw-type confirmation)
    - DISCOVERY: physical SimHat has PCB cutouts the cylinder scan missed.
    Slab cross-section innerWires: 13.9x12.6 oval INSIDE relay footprint
    (keep-out - relay overhangs it; user saw pad poke near it) and
    10.9x1.9 slot past the terminal (benign; bay pad pokes through)
    - Solder-pad risk (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
    [a7670_section.step, antenna_tray_section.step, lilygo_a7670_simhat_carrier.3mf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]
2026-08-17 feat: hybrid photo-textured rendering + turntable video (local-only)
    - scripts/make_hybrid.py: LILYGO product photos (T-SimHat.jpg relay side,
    H559_8.jpg socket side, auto-cropped; board-split via column-density
    valley) mapped as textures onto planes at the true flipped-SimHat
    position between CAD carrier + A7670 STEP
    - outputs: exports/lilygo_hybrid_assembly.glb (photo textures on 3D,
    rotatable in any GLB viewer incl. browsers), renders/hybrid_{iso,top,
    under}.png, analysis/hybrid_alignment.json (honest aspect evidence:
    angled marketing photos stretch ~1.75x on the plane - recorded, not
    hidden), exports/hybrid_turntable.mp4 (240f/30fps full orbit, git-
    ignored *.mp4, served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
2026-08-18 feat: fiducial-mapped photo textures — 6-view sheet decoded, perspective-rectified
    - H559_8.jpg re-analyzed per user: it is a SIX-view contact sheet (4
    end-on corners + top face + under face); center-bottom cell holds TWO
    boards side-by-side (left-center/right-center views)
    - scripts/orient_photos.py: downloads photos, segments the sheet,
    perspective-rectifies each face view via 4-point corner homography to
    the true 33:94.8 aspect, then picks one of 8 orientations by fiducial
    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
2026-08-18 feat: photobake tool + fiducial photo bake for BOTH boards; underside-mirror fix
    - tools/photobake.py + tools/photobake_jobs.json: declarative photo-to-CAD
    pipeline (crop -> perspective-rectify -> 8-orientation fiducial scoring
    -> textured planes at true CAD positions -> GLB + stills + turntable).
    Reusable for future enclosure work; jobs file is the whole config.
    - SimHat component-side photo (verified: sockets far end, 112k silver px)
    now correctly U-mirrored on the down-facing plane (the wrong-image bug
    the user caught in the video); socket-side photo on top face
    - A7670 gets photorealistic overlay too (T-SIMA7670E_6 sheet: left cell =
    component side per vision, right = battery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
2026-08-18 feat: screwless christmas-tree snap plugs + CRITICAL hole-position fix + render plane fix
    Screwless A7670 mounting (user has no screws; A7670_MOUNT=snap_plugs):
    - Ø1.10 shaft through the PCB holes + 2 stacked tapered fins (Ø1.55/1.65)
    above the board, cross-slotted into 4 fingers; <=0.15mm/finger flex
    (commercial board-lock pattern; research: print-in-place snap
    standoffs / snap-fit drill-hole plugs)
    - Fins exist only above the PCB plane -> seated boolean checks clean by
    construction; new probes: hole-band annulus clear + fin presence
    CRITICAL fix caught by those checks: DXF DIMENSION defpoints (and the
    analysis JSON derived like them) are callout anchors ~(+0.31,-0.22) off
    the TR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
    [a7670_section.step, a7670_section.stl, lilygo_a7670_simhat_carrier.3mf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]
2026-08-18 fix: sparse antenna floor, plug bay x=42.5, guide h=2.5mm, watertight seam sink 0.3mm; 34/34 checks pass; carrier 22g PETG (was 40g)
    [antenna_tray_section.step, antenna_tray_section.stl]
2026-08-18 fix: v0.3 print feedback — connector mating-envelope analyzer (catches fence-over-P1), sweep-safe fence relocation with friction bite, screws default, snug ends
    - cad/connectors.py: auto-derived side/end-exit mating envelopes from measured
    solids (TurboCase pattern); proven FAIL on old fences (340mm3 CAN-port block,
    49mm3 P1 block) -> new check simhat_connector_mating_clear
    - fences: (-1, 10.5) biting (0.2mm/side friction grip), (+1, 33.1) locator;
    both in analyzer-legal windows with 3.6mm slide-sweep margin to edge-flush parts
    - SIMHAT_END_PLAY 0.3->0.1 (lip wall + clip arms), HOOK_ENGAGE 1.0->1.3 (rattle)
    - A7670_MOUNT default screws (snap plugs printed unreliable)
    - low-profile fr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
    [a7670_section.step, a7670_section.stl, lilygo_a7670_simhat_carrier.3mf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]
2026-08-18 feat: antenna +X side tray with coax clips — position chosen by boolean elimination
    - ANT_POS=side_tray default: open tray on the A7670 outer edge between the
    two +X ear slots; chamfered mouth, +Y stop, grooved drop-in coax posts on
    the ring-rail top (cable runs along the frame edge to the SMA jacks)
    - elimination evidence: mid-channel impossible (cage hardware cuts 20.8mm
    channel to 17.3mm clear vs 21.2 needed), SimHat shelf blocks its +30mm
    removal lift, end tray 237mm vs 175mm bed — recorded as AGENTS.md rule 43
    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
    [a7670_section.step, a7670_section.stl, lilygo_a7670_simhat_carrier.3mf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]
2026-08-21 ci: fix render pipeline — frozen deps + single-thread OCP (exit 139 segfault on runners)
2026-08-21 ci: install headless GL (EGL/OSMesa) — VTK offscreen segfault root cause
2026-08-21 chore: regenerated exports/renders (single-thread rebuild — matches CI config)
    [a7670_section.step, lilygo_a7670_simhat_carrier.3mf, lilygo_a7670_simhat_carrier.step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]
2026-08-21 feat: A7670 mating envelopes auto-derived (B2) — USB-C/SMA/edge parts via ROT_180-aware mapping, z-gated above PCB to spare standoff bosses; check renamed connector_mating_clear (35/35)
2026-08-21 feat: photobake audit loop (B3) + SimHat texture fixes (B4) — all faces PASS
    - scripts/audit_photobake.py: closed-loop gates — plane placement recomputed
    from placed STEP solids (never hand formulas), fiducial centroids vs CAD
    truth with per-face class map (gated only where unambiguous), fiducial
    mass floors; a7670 orientation advisory (STEP carries no color facts)
    - simhat_up: H559_8 comp88-right board (was: both boards + bezel -> 99% dark,
    silver cu 0.935); now silver 423k @ (0.52,0.22) vs truth (0.5,0.216)
    - simhat_down: flat_dark by documented design — every photo candidate fails
    audit honestly (severed mask / two-boards-squeezed / variant board);
    face is only visible f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
2026-08-21 feat: B1 CI validate matrix (full+low) + A1 heat-set insert ears (parametric, default slots) + A3 docs v0.4 refresh
    - CI: validate job, both profiles, frozen deps, single-thread OCP
    - EAR_MOUNT='inserts': M3x5 brass heat-set pockets in bossed corner ears
    (validated: single solid, 4/4 pockets open); default stays 'slots' until
    inserts are in hand — flip is one line in cad/parameters.py
    - docs/print_settings.md + docs/assembly.md: v0.4 order (carrier first,
    coupon conditional), screws default, side-tray antenna install
2026-10-08 feat: vendor nucula NFC enclosure project (KiCad-driven, 57/57 boolean checks)
    Second board project under this repo's methodology: ESP32-C3 + NFC coil
    enclosure, all board geometry parsed from nucula-v2.kicad_pcb (committed
    analysis/*.json make it runnable without the KiCad source). Includes the
    render.py placeholder-path fix (battery/glass STLs resolve to exports/;
    loader errors fail fast) + trap note in nucula/AGENTS.md. Verified on this
    repo's frozen env (cadquery 2.8): 57/57 checks, STLs byte-identical to the
    shipped ones, all 22 renders regenerate.
    Ultraworked with [Sisyphus](https://github.com/code-yeongyu/oh-my-openagent)
    [ESP32-C3-WROOM-02-N4.step]
2026-10-08 feat: nucula committed exports (STEP/STL per variant + parts manifest)
    Tracked artifacts per repo convention: exports are committed (GitHub
    in-browser STL viewer), renders stay generated (renders/ ignore rule).
    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
    [V0_calibration_coupon.step, V0_calibration_coupon.stl, V1_bottom_shell.step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]
2026-10-08 ci: validate-nucula job (57 boolean checks, frozen deps, OMP pinned)
    Mirrors the existing validate matrix; nucula analysis/*.json are
    committed so no KiCad checkout is needed.
    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
2026-10-08 docs: repo-scope note + README section for the nucula enclosure target
    AGENTS.md gains the two-project scope paragraph (self-pathed scripts,
    no cross-imports); README gets a short section with run commands and
    the 57/57 verification status.
    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
2026-10-08 chore: nucula enclosure moves to its own repo Amperstrand/nucula-enclosure
    Single source of truth (rule 8): the vendored copy and the canonical
    repo would diverge. The canonical repo carries its own CI (Validate
    workflow), the render placeholder fix, and standalone docs; this repo
    keeps a related-project pointer + the framework-seed scope note in
    AGENTS.md (target #2 of the case-building methodology). Also corrects
    the stale '(private)' label — the repo is public.
    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
    [ESP32-C3-WROOM-02-N4.step, V0_calibration_coupon.step, V0_calibration_coupon.stl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]
2026-10-10 docs: prompt library extracted to Amperstrand/enclosure-forge; scope note updated
    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
